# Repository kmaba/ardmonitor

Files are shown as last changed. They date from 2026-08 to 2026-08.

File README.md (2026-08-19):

# ardmonitor

Smart USB desktop monitor running on an Arduino Mega 2560 (or Uno) with a 16×2 I2C LCD, push button, and piezo buzzer.

Supports **Full Mode** (connected to home server) and **Mini / Companion Mode** (lightweight desktop companion for Windows/Linux/macOS).

---

## Features

### 1. Dual Operating Modes
- **Full Homeserver Mode (6 Screens)**:
  - **Clock**: Big 3×2 custom-glyph `HH:MM` display (12-hour, ticking, default screen).
  - **Pi-hole**: DNS request count on the left, blocking percentage on the right.
  - **3D Printer (Moonraker / Klipper)**: Solid+mesh progress bar, remaining time, scrolling filename, temperatures. Auto-switches to this slide when a print starts.
  - **Weather**: Real-time temperature, humidity, wind speed, and weather conditions (Open-Meteo).
  - **Azaan / Prayer Times**: Next prayer name with live countdown in hours/minutes (AlAdhan).
  - **Network**: WiFi SSID, signal strength, and tailnet / local IP.
- **Companion / Mini Mode (3 Screens)**:
  - Automatically activates when running the standalone `companion.py` script.
  - Reduces slides to: **Clock · Weather · Azaan**.

### 2. Physical & Virtual Controls
- **Short Press**: Cycle active screens / navigate menus.
- **Long Press (900ms)**: Open contextual action menu (e.g. Pause/Resume/Cancel print, toggle Pi-hole adblock, manual sync).
- **Super Long Press (3s)**: Toggle LCD backlight on/off.
- **Virtual Button**: Web panel replicates physical button hold gestures (`short`, `long`, `super`).

---

## Hardware & Wiring

- **Board**: Arduino Mega 2560 (recommended for SRAM headroom) or Arduino Uno R3.
- **Display**: 16×2 HD44780 LCD with PCF8574 I2C backpack (Address `0x27`).
- **Button**: Pin **D8** → GND (`INPUT_PULLUP`, active LOW).
- **Buzzer**: Pin **D9** → GND.

### I2C Pin Connections:
| Board | SDA | SCL | VCC | GND |
|---|---|---|---|---|
| **Arduino Mega 2560** | Pin **20** | Pin **21** | 5V | GND |
| **Arduino Uno R3** | Pin **A4** | Pin **A5** | 5V | GND |

---

## Software

### 1. Arduino Firmware (`HomeMonitor.ino`)
Compile and flash using Arduino IDE or `arduino-builder`:
```sh
# For Mega 2560:
arduino-builder -fqbn arduino:avr:mega:cpu=atmega2560 HomeMonitor.ino
# For Uno:
arduino-builder -fqbn arduino:avr:uno HomeMonitor.ino
```

### 2. Standalone Companion App
Cross-platform lightweight driver for Windows, Linux, and macOS. Auto-detects the Arduino on any USB/COM port, sets the Arduino to Mini Mode, and streams local clock, weather, and prayer times:

- **Windows (`companion.bat`)**:
  - Fully automated 1-click bootstrap.
  - Automatically downloads `companion.py` from GitHub if missing.
  - Prompts for UAC and installs Python 3 if not present on the system.
  - Auto-installs `pyserial` and connects to the display.
- **Linux / macOS (`companion.sh`)**:
  - Automatically downloads `companion.py` if missing.
  - Auto-installs Python 3 via system package manager (apt/pacman/dnf/brew) if needed.
  - Auto-installs `pyserial` and runs the driver.
- **Manual**:
  ```sh
  pip install pyserial
  python companion.py
  ```

### 3. Full Home Server Bridge (`homemonitor_bridge.py`)
Runs as a systemd service on a home server or PC connected to the Arduino. Polls Pi-hole v6 API, Moonraker Klipper API, weather, and azaan, and serves a mobile-responsive web controller at `http://localhost:8080`.

---

## 3D Printable Enclosure

The `enclosure.scad` file provides a friction-fit 2-piece case with exact cutouts for the LCD, side USB/power cables, front button, and Arduino PCB standoffs. Pre-rendered STLs (`bottom_shell.stl`, `top_lid.stl`) are included.

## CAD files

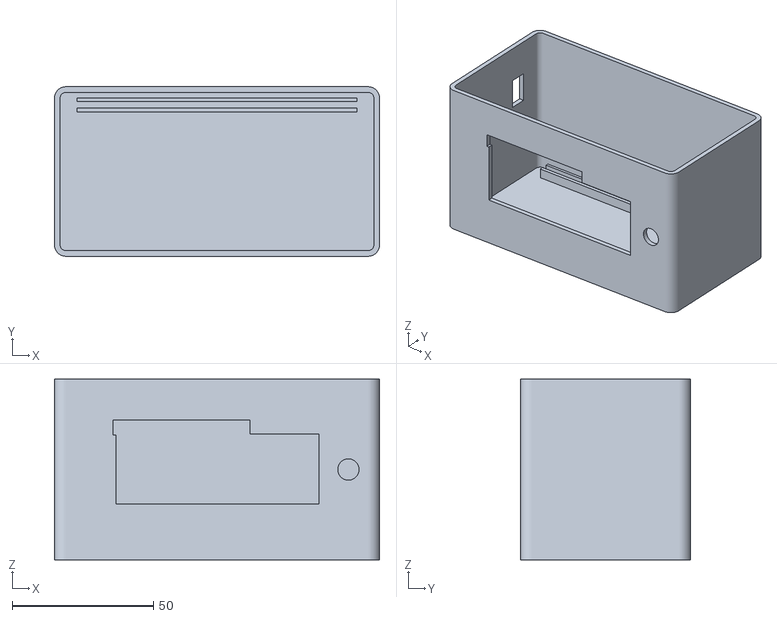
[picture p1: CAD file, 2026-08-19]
bottom_shell.stl
115.0 x 60.0 x 64.0

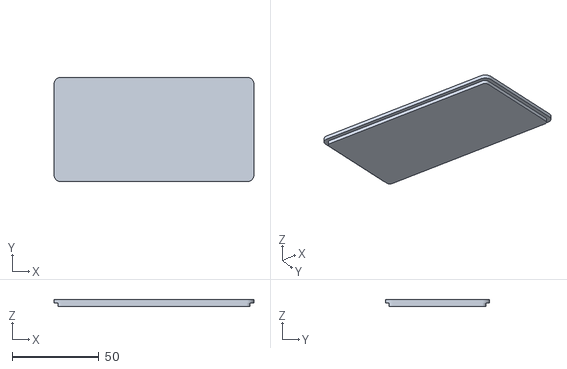
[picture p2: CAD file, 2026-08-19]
top_lid.stl
115.0 x 60.0 x 4.00

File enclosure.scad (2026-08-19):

// Arduino HomeMonitor Enclosure v7 (Optimized Sleek Desktop Edition)
// - Dimensions: 115mm (L) x 60mm (W) x 68mm (H)
// - Wall thickness: 2.0mm, rounded vertical corners (r = 4mm)
// - Front: Centered LCD window + 5mm (0.5cm) pin-clearance notch directly above LCD window
// - Left: Single USB cutout raised +3mm (Center Z = 43mm / 4.3cm) with halved width (Width Y = 7.0mm)

$fn = 60;

/* ===== ENCLOSURE DIMENSIONS ===== */
outer_x = 115.0;
outer_y = 60.0;                 // Slim 60mm depth
outer_z = 68.0;                 // 68mm compact height
wall    = 2.0;                  // 2.0mm wall thickness
corner_r = 4.0;                 // Rounded corners (r = 4mm)
tol     = 0.35;                 // 3D print tolerance
BOX_H   = 64.0;                 // Bottom shell height (Lid = 4.0mm)

/* ===== HELPER: ROUNDED RECTANGLE CUBE ===== */
module rounded_box(dim, r) {
    x = dim[0]; y = dim[1]; z = dim[2];
    hull() {
        translate([r, r, 0]) cylinder(r=r, h=z);
        translate([x - r, r, 0]) cylinder(r=r, h=z);
        translate([r, y - r, 0]) cylinder(r=r, h=z);
        translate([x - r, y - r, 0]) cylinder(r=r, h=z);
    }
}

/* ===== BASE SHELL ===== */
module shell() {
    difference() {
        rounded_box([outer_x, outer_y, outer_z], corner_r);
        // Hollow interior
        translate([wall, wall, wall])
            rounded_box([outer_x - 2*wall, outer_y - 2*wall, outer_z], max(1.0, corner_r - wall));
    }
}

module bottom_box() {
    intersection() {
        shell();
        cube([outer_x, outer_y, BOX_H]);
    }
}

module top_lid() {
    inner_x = outer_x - 2*wall;
    inner_y = outer_y - 2*wall;
    inner_r = max(1.0, corner_r - wall);

    translate([0, 0, BOX_H]) {
        // Inner locating rim (slides into box opening)
        translate([wall + 0.25, wall + 0.25, 0])
            rounded_box([inner_x - 0.5, inner_y - 0.5, outer_z - BOX_H - wall], inner_r);
        // Top plate
        translate([0, 0, outer_z - BOX_H - wall])
            rounded_box([outer_x, outer_y, wall], corner_r);
    }
}

/* ===== FRONT PANEL CUTOUTS (Y = 0) ===== */
LCD_W = 71.5;
LCD_H = 24.5;
LCD_X = (outer_x - LCD_W) / 2;       // 21.75 mm (centered in X)
LCD_Z = (BOX_H - LCD_H) / 2;         // 19.75 mm (centered in Z)

BUTTON_X = 104.0;
BUTTON_Z = LCD_Z + LCD_H / 2;         // Aligned with LCD center
BUTTON_D = 7.2;

// Pin header notch: 48mm wide, exactly 5mm (0.5cm) directly above top edge of LCD
NOTCH_W = 48.0;
NOTCH_H = 5.0;                       // 5mm (0.5cm) height directly above screen cutout

module front_cutouts() {
    // 1. Main LCD glass window
    translate([LCD_X, -1, LCD_Z])
        cube([LCD_W + tol, wall + 2, LCD_H + tol]);

    // 2. 5mm (0.5cm) pin-header notch directly above the LCD window's top edge
    translate([LCD_X - 1, -1, LCD_Z + LCD_H])
        cube([NOTCH_W + tol, wall + 2, NOTCH_H + tol]);

    // 3. Panel button hole
    translate([BUTTON_X, wall + 2, BUTTON_Z])
        rotate([90, 0, 0])
        cylinder(d=BUTTON_D + tol, h=wall + 4);
}

/* ===== LEFT WALL CUTOUTS (X = 0) ===== */
// USB cutout:
// Center: Z = 43.0mm (4.3cm), Y = 44.0mm (4.4cm)
// Width: 7.0mm (halved from 14mm)
// Height: 12.0mm
// Bottom edge of hole: Z = 37.0mm (3.7cm from outer base)
// Top edge of hole: Z = 49.0mm (4.9cm from outer base)
USB_Y = 44.0;
USB_Z = 43.0;                        // Moved +0.3cm (3.0mm) up
USB_W = 7.0;                         // Halved width (7.0mm)
USB_H = 12.0;

module left_cutouts() {
    translate([-1, USB_Y - USB_W/2, USB_Z - USB_H/2])
        cube([wall + 2, USB_W + tol, USB_H + tol]);
}

/* ===== LIGHTWEIGHT MEGA GUIDE RAIL ===== */
module board_guide() {
    // Slim vertical guide rails on the floor
    translate([wall + 6, outer_y - wall - 7, wall])
        difference() {
            cube([outer_x - 2*wall - 12, 5.0, 4.0]);
            translate([-1, 1.5, 1.5])
                cube([outer_x - 2*wall - 10, 2.0 + tol, 3.0]);
        }
}

/* ===== ASSEMBLY ===== */
module assembled() {
    color("DimGray", 0.9) bottom_box();
    color("SlateGray", 0.85) top_lid();

    // Visual: LCD module (Green)
    color("DarkGreen", 0.7)
        translate([(outer_x - 80)/2, wall, LCD_Z - 5])
        cube([80, 9, 36]);

    // Visual: Vertical Mega (Blue)
    color("DodgerBlue", 0.7)
        translate([wall + 4, outer_y - wall - 6, wall + 2])
        cube([101.6, 2.0, 53.3]);
}

/* ===== EXPORTS ===== */
module print_bottom() {
    difference() {
        union() {
            bottom_box();
            board_guide();
        }
        front_cutouts();
        left_cutouts();
    }
}

module print_top() {
    top_lid();
}

assembled();

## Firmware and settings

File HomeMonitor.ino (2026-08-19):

/*
 * HomeMonitor (PC-driven) — Uno + 16x2 I2C LCD (0x27)
 * Buzzer D9, button D8 (button -> GND, INPUT_PULLUP, active LOW).
 *
 * PC streams data (P:/R:/N:/C:/S:/MSG:). Arduino -> PC:
 *   ADBLOCK:ON | ADBLOCK:OFF[:<sec>]
 *   PRINT:PAUSE | PRINT:RESUME | PRINT:CANCEL
 *   GCODE:HOME | GCODE:EXTRUDE | GCODE:RETRACT
 *   TEMP:PLA | TEMP:PETG | TEMP:OFF
 *   PING | NOTIFY | SYNC
 * UI: short press cycles screens; hold opens context menu (bar fills on the
 * BOTTOM row only); in menu short-press moves, long-press selects.
 */
#include <Wire.h>
#include <LiquidCrystal_I2C.h>

LiquidCrystal_I2C lcd(0x27, 16, 2);

const int BUTTON_PIN = 8;    // button -> GND, INPUT_PULLUP, active LOW
const int BUZZER_PIN = 9;

// ---------------- sounds (very quiet, monotone, 25% duty) ----------------
void quietTone(unsigned int freq, unsigned int ms) {
  unsigned long period = 1000000UL / freq;
  unsigned long on = period * 25 / 100;
  unsigned long off = period - on;
  unsigned long end = millis() + ms;
  while ((long)(end - millis()) > 0) {
    digitalWrite(BUZZER_PIN, HIGH);
    delayMicroseconds(on);
    digitalWrite(BUZZER_PIN, LOW);
    delayMicroseconds(off);
  }
  digitalWrite(BUZZER_PIN, LOW);
}
void beep()       { quietTone(440, 40); }
void beepSelect() { quietTone(440, 110); }

// ---------------- screens ----------------
enum { SCR_PIHOLE, SCR_PRINT, SCR_WEATHER, SCR_AZAAN, SCR_NET, SCR_CLOCK, SCR_COUNT };
int screen = SCR_CLOCK;
int prevScreen = -1;
bool companionMode = false;
const char* screenNames[SCR_COUNT] = { "Pi-hole", "Print", "Weather", "Azaan", "Network", "Clock" };

char scrL1[SCR_COUNT][17];
char scrL2[SCR_COUNT][17];
bool scrHas[SCR_COUNT] = { false, false, false, false, false, false };

char printState[10] = "standby";
char printFname[21] = "";
int  pPct = 0, pE = 0, pET = 0, pB = 0, pBT = 0, pElapsed = 0;

// live clock state (from C: line, ticks locally)
byte clkH = 0, clkM = 0, clkS = 0;
int  clkDay = 0, clkMon = 0, clkYr = 0;
char clkBlk[4] = "?";
unsigned long clkSyncMs = 0;
bool clockValid = false;

// pi-hole stats (requests + blocked %)
long piholeQueries = 0;
long piholeBlocked = 0;
int piholePct = 0;
// weather (temp stored as degC * 10, e.g. 234 = 23.4C)
int wTemp10 = 0;
int wHum = 0, wWind = 0, wCode = 0;
// azaan prayer times "HH:MM" (24h)
char az[5][6];

// ---------------- menu ----------------
typedef struct { const char* label; const char* cmd; } MenuItem;

MenuItem piholeMenu[] = {
  { "Back", "" },
  { "Adblock ON", "ADBLOCK:ON" },
  { "Adblock OFF", "ADBLOCK:OFF:0" },
  { "Off 10s", "ADBLOCK:OFF:10" },
  { "Off 30s", "ADBLOCK:OFF:30" },
  { "Off 1m", "ADBLOCK:OFF:60" },
  { "Off 5m", "ADBLOCK:OFF:300" },
  { "Off 1h", "ADBLOCK:OFF:3600" },
};
MenuItem printIdle[] = {
  { "Back", "" },
  { "Home", "GCODE:HOME" },
  { "Extrude 10mm", "GCODE:EXTRUDE" },
  { "Retract 10mm", "GCODE:RETRACT" },
  { "Preheat PLA", "TEMP:PLA" },
  { "Preheat PETG", "TEMP:PETG" },
  { "Cooldown", "TEMP:OFF" },
};
MenuItem printBusy[] = {
  { "Back", "" },
  { "Pause", "PRINT:PAUSE" },
  { "Cancel", "PRINT:CANCEL" },
  { "Cooldown", "TEMP:OFF" },
};
MenuItem printPaused[] = {
  { "Back", "" },
  { "Resume", "PRINT:RESUME" },
  { "Cancel", "PRINT:CANCEL" },
  { "Cooldown", "TEMP:OFF" },
};
MenuItem netMenu[] = {
  { "Back", "" },
  { "Ping server", "PING" },
  { "Notify Discord", "NOTIFY" },
};
MenuItem clockMenu[] = {
  { "Back", "" },
  { "Sync now", "SYNC" },
};
MenuItem simpleMenu[] = {
  { "Back", "" },
  { "Sync now", "SYNC" },
};

MenuItem* menuItems = NULL;
const char* menuTitle = "";
int menuLen = 0;
int menuIdx = 0;

// ---------------- UI state ----------------
enum { ST_SCREEN, ST_MENU } state = ST_SCREEN;

char msg1[17] = "";
char msg2[17] = "";
unsigned long msgUntil = 0;
const unsigned long MSG_MS = 2500;

// ---------------- button (debounced edges, active LOW) ----------------
const unsigned long DEBOUNCE = 50;
const unsigned long LONG_MS = 900;
const unsigned long SUPER_LONG_MS = 3000;

bool redraw = true;                 // force full redraw after a screen switch / data change

bool btnPrev = false;
bool btnNow = false;
unsigned long lastBtnChange = 0;
unsigned long btnDownMs = 0;
bool longFired = false;
bool superLongFired = false;
bool backlightOn = true;
int lastBarCells = -1;

void shortPressAction() {
  beep();
  redraw = true;
  if (state == ST_MENU) {
    menuIdx = (menuIdx + 1) % menuLen;
  } else if (companionMode) {
    // Companion mode: only cycle Weather, Azaan, Clock
    if (screen == SCR_WEATHER) screen = SCR_AZAAN;
    else if (screen == SCR_AZAAN) screen = SCR_CLOCK;
    else screen = SCR_WEATHER;
  } else {
    screen = (screen + 1) % SCR_COUNT;
  }
}

void selectOption() {
  const char* cmd = menuItems[menuIdx].cmd;
  if (strcmp(cmd, "") == 0) {                 // Back
    state = ST_SCREEN;
  } else {
    Serial.println(cmd);
    state = ST_SCREEN;
    strncpy(msg1, menuItems[menuIdx].label, 16); msg1[16] = 0;
    strcpy(msg2, "sent to PC");
    msgUntil = millis() + MSG_MS;
  }
  redraw = true;
}

void enterPrintMenu() {
  if (strcmp(printState, "printing") == 0)      { menuItems = printBusy; menuLen = 4; }
  else if (strcmp(printState, "paused") == 0)   { menuItems = printPaused; menuLen = 4; }
  else                                          { menuItems = printIdle; menuLen = 7; }
  menuTitle = "Print";
}

void longPressAction() {
  beepSelect();
  redraw = true;
  if (state == ST_MENU) {
    selectOption();
  } else {
    state = ST_MENU;
    menuIdx = 0;
    switch (screen) {
      case SCR_PIHOLE:
        menuItems = piholeMenu; menuLen = sizeof(piholeMenu) / sizeof(MenuItem); menuTitle = "Pi-hole"; break;
      case SCR_PRINT:
        enterPrintMenu(); break;
      case SCR_NET:
        menuItems = netMenu; menuLen = sizeof(netMenu) / sizeof(MenuItem); menuTitle = "Network"; break;
      case SCR_CLOCK:
        menuItems = clockMenu; menuLen = sizeof(clockMenu) / sizeof(MenuItem); menuTitle = "Clock"; break;
      case SCR_WEATHER:
      case SCR_AZAAN:
        menuItems = simpleMenu; menuLen = sizeof(simpleMenu) / sizeof(MenuItem); menuTitle = screenNames[screen]; break;
    }
  }
}

void toggleBacklight() {
  backlightOn = !backlightOn;
  if (backlightOn) lcd.backlight(); else lcd.noBacklight();
  beep();
  state = ST_SCREEN;
  redraw = true;
}

void updateButton() {
  unsigned long now = millis();
  bool raw = (digitalRead(BUTTON_PIN) == LOW);
  if (raw != btnPrev) {
    btnPrev = raw;
    lastBtnChange = now;
  }
  if (now - lastBtnChange >= DEBOUNCE) {
    if (raw != btnNow) {
      btnNow = raw;
      if (btnNow) {
        btnDownMs = now;
        longFired = false;
        superLongFired = false;
        lastBarCells = -1;
      } else if (!longFired) {
        shortPressAction();
      }
    }
  }
  if (btnNow && !longFired && (now - btnDownMs) >= LONG_MS) {
    longFired = true;
    longPressAction();
  }
  if (btnNow && !superLongFired && (now - btnDownMs) >= SUPER_LONG_MS) {
    superLongFired = true;
    toggleBacklight();
  }
}

// ---------------- LCD ----------------
char lineCache[2][17];

void lcdLine(int row, const char* s) {
  char line[17];
  strncpy(line, s, 16);
  line[16] = 0;
  for (int i = strlen(line); i < 16; i++) line[i] = ' ';
  line[16] = 0;
  if (!redraw && strncmp(line, lineCache[row], 16) == 0) return;
  strncpy(lineCache[row], line, 16);
  lcd.setCursor(0, row);
  lcd.print(line);
}

// custom bar glyphs: solid fill columns + mesh-hatch for the unfilled track
void createBarChars() {
  for (int fill = 0; fill <= 5; fill++) {
    byte bm[8];
    for (int r = 0; r < 8; r++) {
      byte v = 0;
      for (int c = 0; c < 5; c++) {
        bool on = (c < fill) || ((c + r) % 2 == 0);   // filled=solid, rest=mesh
        if (on) v |= (1 << (4 - c));
      }
      bm[r] = v;
    }
    lcd.createChar(fill, bm);
  }
}

// ---- big 3x2 digits (8 segment glyphs, HD44780 slots 0-7) ----
byte segLT[8]  = { B00111, B11111, B11111, B11111, B11111, B11111, B11111, B11111 };
byte segUB[8]  = { B11111, B11111, B11111, B00000, B00000, B00000, B00000, B00000 };
byte segRT[8]  = { B11100, B11111, B11111, B11111, B11111, B11111, B11111, B11111 };
byte segLL[8]  = { B11111, B11111, B11111, B11111, B11111, B11111, B11111, B00111 };
byte segLB[8]  = { B00000, B00000, B00000, B00000, B00000, B11111, B11111, B11111 };
byte segLR[8]  = { B11111, B11111, B11111, B11111, B11111, B11111, B11111, B11100 };
byte segUMB[8] = { B11111, B11111, B11111, B00000, B00000, B00000, B11111, B11111 };
byte segLMB[8] = { B11111, B00000, B00000, B00000, B00000, B11111, B11111, B11111 };

int glyphMode = 0;   // 0 = bar glyphs (print), 1 = big-digit glyphs (clock)

void createBigDigitChars() {
  lcd.createChar(0, segLT);
  lcd.createChar(1, segUB);
  lcd.createChar(2, segRT);
  lcd.createChar(3, segLL);
  lcd.createChar(4, segLB);
  lcd.createChar(5, segLR);
  lcd.createChar(6, segUMB);
  lcd.createChar(7, segLMB);
}

void ensureBarGlyphs() {
  if (glyphMode == 0) return;
  createBarChars();
  glyphMode = 0;
}

void ensureBigDigitGlyphs() {
  if (glyphMode == 1) return;
  createBigDigitChars();
  glyphMode = 1;
}

void drawBigDigit(int col, int d) {
  // clear the digit cell first so partial digits (1,4,7,9) leave no stale blocks
  lcd.setCursor(col, 0); lcd.print("   ");
  lcd.setCursor(col, 1); lcd.print("   ");
  switch (d) {
    case 0:
      lcd.setCursor(col, 0); lcd.write(0); lcd.write(1); lcd.write(2);
      lcd.setCursor(col, 1); lcd.write(3); lcd.write(4); lcd.write(5); break;
    case 1:
      lcd.setCursor(col + 1, 0); lcd.write(2);
      lcd.setCursor(col + 1, 1); lcd.write(5); break;
    case 2:
      lcd.setCursor(col, 0); lcd.write(6); lcd.write(6); lcd.write(2);
      lcd.setCursor(col, 1); lcd.write(3); lcd.write(7); lcd.write(7); break;
    case 3:
      lcd.setCursor(col, 0); lcd.write(6); lcd.write(6); lcd.write(2);
      lcd.setCursor(col, 1); lcd.write(7); lcd.write(7); lcd.write(5); break;
    case 4:
      lcd.setCursor(col, 0); lcd.write(0); lcd.write(4); lcd.write(2);
      lcd.setCursor(col + 2, 1); lcd.write(5); break;
    case 5:
      lcd.setCursor(col, 0); lcd.write(0); lcd.write(6); lcd.write(6);
      lcd.setCursor(col, 1); lcd.write(7); lcd.write(7); lcd.write(5); break;
    case 6:
      lcd.setCursor(col, 0); lcd.write(0); lcd.write(6); lcd.write(6);
      lcd.setCursor(col, 1); lcd.write(3); lcd.write(7); lcd.write(5); break;
    case 7:
      lcd.setCursor(col, 0); lcd.write(1); lcd.write(1); lcd.write(2);
      lcd.setCursor(col + 2, 1); lcd.write(5); break;
    case 8:
      lcd.setCursor(col, 0); lcd.write(0); lcd.write(6); lcd.write(2);
      lcd.setCursor(col, 1); lcd.write(3); lcd.write(7); lcd.write(5); break;
    case 9:
      lcd.setCursor(col, 0); lcd.write(0); lcd.write(6); lcd.write(2);
      lcd.setCursor(col + 2, 1); lcd.write(5); break;
  }
}

void formatHM(long mins, char* out) {
  if (mins < 0) mins = 0;
  snprintf(out, 8, "%ld:%02ld", mins / 60, mins % 60);
}

// slow scroll window for the filename (half-speed marquee)
void fnameWindow(const char* text, int win, char* out) {
  int len = strlen(text);
  static int sp = 0;
  static unsigned long lastMove = 0;
  if (len > win) {
    if (millis() - lastMove >= 600) {
      lastMove = millis();
      sp++;
      if (sp > len - win) sp = 0;
    }
  } else {
    sp = 0;
  }
  for (int i = 0; i < win; i++) {
    int idx = sp + i;
    out[i] = (idx < len) ? text[idx] : ' ';
  }
  out[win] = 0;
}

// print screen: custom-glyph bar (solid+mesh) + pct on top, remaining + filename below
void renderPrint() {
  static int lastPx = -1, lastPct = -1;
  const int BAR_CHARS = 11;
  int fillPx = (long)pPct * BAR_CHARS * 5 / 100;
  if (redraw || fillPx != lastPx || pPct != lastPct) {
    lastPx = fillPx;
    lastPct = pPct;
    lcd.setCursor(0, 0);
    for (int i = 0; i < BAR_CHARS; i++) {
      int px = fillPx - i * 5;
      lcd.write((uint8_t)(px >= 5 ? 5 : (px > 0 ? px : 0)));
    }
    lcd.write(' ');
    char pbuf[8];
    snprintf(pbuf, 8, "%3d%%", pPct);
    lcd.print(pbuf);
  }

  char l2[17];
  int len = snprintf(l2, 17, "R ");
  char r[8];
  long rem = 0;
  if (pPct > 0) rem = (long)pElapsed * (100 - pPct) / pPct;
  formatHM(rem, r);
  len += snprintf(l2 + len, 17 - len, "%s ", r);
  int win = 16 - len;
  if (win < 3) win = 3;
  fnameWindow(printFname, win, l2 + len);
  lcdLine(1, l2);
}

void currentTime(byte& h, byte& m, byte& s) {
  unsigned long elapsed = (millis() - clkSyncMs) / 1000;
  long ss = clkS + (long)(elapsed % 60);
  long mm = clkM + (long)(elapsed / 60) + ss / 60;
  long hh = clkH + mm / 60;
  s = (byte)(ss % 60);
  m = (byte)(mm % 60);
  h = (byte)(hh % 24);
}

// live ticking big HH:MM clock (12-hour, no AM/PM)
void renderClock(bool first) {
  byte h, m, s;
  currentTime(h, m, s);

  byte h12, md;
  if (!clockValid) {
    h12 = 0; md = 0;                    // 00:00 placeholder until synced
  } else {
    h12 = h % 12; if (h12 == 0) h12 = 12;
    md = m;
  }

  bool colonOn = ((millis() / 500) % 2) == 0;
  static byte lastH = 255, lastM = 255;
  static bool lastColon = false;

  if (first) {
    // just entered the clock screen: clear once, then force full redraw
    lcd.setCursor(0, 0); lcd.print("                ");
    lcd.setCursor(0, 1); lcd.print("                ");
    lastH = 255; lastM = 255; lastColon = !colonOn;
  }

  // incremental: only update the parts that changed (no full-screen clear)
  if (h12 != lastH) {
    lastH = h12;
    drawBigDigit(1, h12 / 10);
    drawBigDigit(5, h12 % 10);
  }
  if (md != lastM) {
    lastM = md;
    drawBigDigit(9, md / 10);
    drawBigDigit(13, md % 10);
  }
  if (colonOn != lastColon) {
    lastColon = colonOn;
    lcd.setCursor(8, 0); lcd.print(colonOn ? ":" : " ");
    lcd.setCursor(8, 1); lcd.print(colonOn ? ":" : " ");
  }
}

// ---- weather ----
const char* weatherDesc(int code) {
  if (code == 0) return "Clear sky";
  if (code == 1) return "Mostly clear";
  if (code == 2) return "Partly cloudy";
  if (code == 3) return "Overcast";
  if (code >= 45 && code <= 48) return "Fog";
  if (code >= 51 && code <= 57) return "Drizzle";
  if (code >= 61 && code <= 67) return "Rain";
  if (code >= 71 && code <= 77) return "Snow";
  if (code >= 80 && code <= 82) return "Showers";
  if (code >= 95 && code <= 99) return "Thunderstorm";
  return "?";
}

void renderWeather() {
  if (!scrHas[SCR_WEATHER]) {
    lcdLine(0, "Weather");
    lcdLine(1, "waiting PC...");
    return;
  }
  char l1[17];
  snprintf(l1, 17, "%d.%dC %d%% %dk/h", wTemp10 / 10, abs(wTemp10 % 10), wHum, wWind);
  lcdLine(0, l1);
  lcdLine(1, weatherDesc(wCode));
}

// ---- azaan: next prayer + countdown ----
void renderAzaan() {
  if (!scrHas[SCR_AZAAN]) {
    lcdLine(0, "Azaan");
    lcdLine(1, "waiting PC...");
    return;
  }
  byte h, m, s;
  currentTime(h, m, s);
  int nowMin = h * 60 + m;

  const char* names[5] = { "Fajr", "Dhuhr", "Asr", "Maghrib", "Isha" };
  int tm[5];
  for (int i = 0; i < 5; i++) {
    tm[i] = ((az[i][0]-'0')*10 + (az[i][1]-'0')) * 60 + ((az[i][3]-'0')*10 + (az[i][4]-'0'));
  }
  int next = -1, nextMin = 0;
  for (int i = 0; i < 5; i++) {
    if (tm[i] > nowMin) { next = i; nextMin = tm[i]; break; }
  }
  if (next < 0) { next = 0; nextMin = tm[0] + 24*60; }   // tomorrow's Fajr

  int diff = nextMin - nowMin;
  char l1[17], l2[17];
  snprintf(l1, 17, "%s %s", names[next], az[next]);
  if (diff >= 60) snprintf(l2, 17, "in %dh %02dm", diff / 60, diff % 60);
  else snprintf(l2, 17, "in %d min", diff);
  lcdLine(0, l1);
  lcdLine(1, l2);
}

// ---- pi-hole: requests left, blocked % right ----
void renderPihole() {
  if (!scrHas[SCR_PIHOLE]) {
    lcdLine(0, "Pi-hole");
    lcdLine(1, "waiting PC...");
    return;
  }
  char l1[17], l2[17];
  snprintf(l1, 17, "Requests   Block");
  snprintf(l2, 17, "%-10ld %4d%%", piholeQueries, piholePct);
  lcdLine(0, l1);
  lcdLine(1, l2);
}

void renderScreen() {
  if (!scrHas[screen]) {
    lcdLine(0, screenNames[screen]);
    lcdLine(1, "waiting PC...");
    return;
  }
  lcdLine(0, scrL1[screen]);
  lcdLine(1, scrL2[screen]);
}

void renderMenu() {
  char buf[17];
  snprintf(buf, 17, "%s %d/%d", menuTitle, menuIdx + 1, menuLen);
  lcdLine(0, buf);
  snprintf(buf, 17, "> %s", menuItems[menuIdx].label);
  lcdLine(1, buf);
}

// bottom-row-only press bar (white squares); top row stays untouched
void renderPressBar() {
  unsigned long dur = millis() - btnDownMs;
  int cells = (int)((long)dur * 16 / LONG_MS);
  if (cells > 16) cells = 16;
  if (cells < 0) cells = 0;
  if (cells != lastBarCells) {
    lastBarCells = cells;
    char bar[17];
    for (int i = 0; i < 16; i++) bar[i] = (i < cells) ? (char)0xFF : ' ';
    bar[16] = 0;
    lcdLine(1, bar);
  }
}

// PC screen removed; this is the main render dispatch
void render() {
  if (btnNow && !longFired) {
    renderPressBar();
    redraw = false;
    prevScreen = -1;
    return;
  }
  if (msgUntil && millis() < msgUntil) {
    lcdLine(0, msg1);
    lcdLine(1, msg2);
    redraw = false;
    prevScreen = -1;
    return;
  }
  if (state == ST_MENU) {
    renderMenu();
    redraw = false;
    prevScreen = -1;
    return;
  }
  if (screen == SCR_PRINT) {
    ensureBarGlyphs();
    renderPrint();
    redraw = false;
    prevScreen = screen;
    return;
  }
  if (screen == SCR_PIHOLE) {
    renderPihole();
    redraw = false;
    prevScreen = screen;
    return;
  }
  if (screen == SCR_WEATHER) {
    renderWeather();
    redraw = false;
    prevScreen = screen;
    return;
  }
  if (screen == SCR_AZAAN) {
    renderAzaan();
    redraw = false;
    prevScreen = screen;
    return;
  }
  if (screen == SCR_CLOCK) {
    ensureBigDigitGlyphs();
    renderClock(screen != prevScreen);
    redraw = false;
    prevScreen = screen;
    return;
  }
  renderScreen();
  redraw = false;
  prevScreen = screen;
}
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
void loop() {
  updateButton();
  drainSerial();
  if (msgUntil && millis() > msgUntil) {
    msgUntil = 0;
    redraw = true;
  }
  render();
  delay(10);
}

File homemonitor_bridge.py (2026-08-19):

#!/usr/bin/env python3
"""
HomeMonitor PC bridge — polls the homeserver (Pi-hole + Moonraker) and the PC's
own stats, streams display data to the Arduino over USB serial, and serves a
web panel to switch slides. Handles commands: ADBLOCK, PRINT, GCODE, TEMP,
PING, NOTIFY, SYNC.
"""
import sys, time, json, glob, subprocess, queue, threading
import urllib.request
from http.server import BaseHTTPRequestHandler, HTTPServer

SERVER = "100.125.116.96"   # kmaba-server tailnet IP (stable)
WEB_PORT = 8080
DISCORD = ("https://discord.com/api/webhooks/1494662807583723560/"
           "CFqfNB9Mqif49FdWwG6zjo6NQ_7LalfB1S-mOn-VqaXiOnZtR7AxsOpUt2ETkecqO9xG")

screen_cmds = queue.Queue()
serial_cmds = queue.Queue()   # generic serial commands (e.g. virtual-button gestures)

last_pst = None            # previous Moonraker print state, for auto-switch
current_pst = "?"          # most recent print state from poll()

PAGE = """<!doctype html><html><head><meta charset="utf-8"><meta name="viewport" content="width=device-width, initial-scale=1"><title>HomeMonitor</title>
<style>
*{box-sizing:border-box}
body{background:#0b0f14;color:#e6e6e6;font-family:system-ui,-apple-system,sans-serif;margin:0;padding:24px 16px;display:flex;justify-content:center}
.wrap{width:100%;max-width:380px;display:flex;flex-direction:column;align-items:center;gap:12px}
h1{font-size:22px;font-weight:600;margin:0 0 4px}
p{color:#8fa3b8;font-size:13px;margin:0 0 8px;text-align:center}
.btn{width:100%;padding:15px;border:none;border-radius:12px;font-size:17px;cursor:pointer;color:#fff;background:#1c2733;border:1px solid #2f4254;-webkit-tap-highlight-color:transparent}
.btn:active{background:#263647}
.btn.on{background:#2e6b4f;border-color:#4d9c78}
.vbtn{width:150px;height:150px;border-radius:50%;border:3px solid #2f4254;background:#1c2733;color:#fff;font-size:20px;display:flex;align-items:center;justify-content:center;cursor:pointer;user-select:none;-webkit-user-select:none;touch-action:none;-webkit-tap-highlight-color:transparent;transition:background .15s;margin-top:8px}
.vbtn.holding{background:#33405a;border-color:#5a7a9c}
.vbtn.held-long{background:#8a6d1f;border-color:#c9a227}
.vbtn.held-super{background:#1f5a8a;border-color:#2a7ac9}
#status{color:#9fb3c8;font-size:13px;min-height:18px;text-align:center}
@media (min-width:600px){ .btn{width:280px} }
</style></head><body>
<div class="wrap">
<h1>HomeMonitor</h1>
<p>choose the slide shown on the Arduino display</p>
<button class="btn" data-n="0">Pi-hole</button>
<button class="btn" data-n="1">Print</button>
<button class="btn" data-n="2">Weather</button>
<button class="btn" data-n="3">Azaan</button>
<button class="btn" data-n="4">Network</button>
<button class="btn" data-n="5">Clock</button>
<p style="margin-top:16px">virtual button &mdash; click: short, hold 1s: menu, hold 3s: backlight</p>
<div class="vbtn" id="vbtn">HOLD</div>
<div id="status"></div>
</div>
<script>
function go(n){fetch('/screen?n='+n).then(function(r){return r.text()}).then(function(){mark(n)}).catch(function(){document.getElementById('status').textContent='failed'});}
function mark(n){var b=document.querySelectorAll('.btn');b.forEach(function(x,i){x.classList.toggle('on',i==n);});}
var b=document.querySelectorAll('.btn');b.forEach(function(x){x.onclick=function(){go(x.getAttribute('data-n'));};});
function sendBtn(a){fetch('/btn?action='+a).then(function(){var m={short:'short press',long:'long press (menu)',super:'backlight toggle'};document.getElementById('status').textContent=m[a]||a;}).catch(function(){document.getElementById('status').textContent='failed'});}
(function(){
  var el=document.getElementById('vbtn'),fired=0,tL,tS;
  function down(e){if(e.cancelable)e.preventDefault();fired=0;el.classList.add('holding');
    tL=setTimeout(function(){fired=1;el.classList.add('held-long');sendBtn('long');},1000);
    tS=setTimeout(function(){fired=2;el.classList.add('held-super');sendBtn('super');},3000);}
  function up(){clearTimeout(tL);clearTimeout(tS);el.classList.remove('holding','held-long','held-super');if(fired===0)sendBtn('short');}
  el.addEventListener('mousedown',down);el.addEventListener('mouseup',up);el.addEventListener('mouseleave',up);
  el.addEventListener('touchstart',down,{passive:false});el.addEventListener('touchend',up);el.addEventListener('touchcancel',up);
})();
</script></body></html>"""

DL_PAGE = """<!doctype html><html><head><meta charset="utf-8"><meta name="viewport" content="width=device-width, initial-scale=1"><title>kmaba.link/d</title>
<style>
body{background:#0b0f14;color:#eee;font-family:system-ui,sans-serif;margin:0;padding:32px 16px;display:flex;justify-content:center}
.wrap{width:100%;max-width:400px}
h1{font-size:24px;margin:0 0 4px}
p{color:#8fa3b8;font-size:14px;margin:0 0 16px}
.card{background:#1c2733;border:1px solid #2f4254;border-radius:12px;padding:20px}
a.dl{display:block;background:#2e6b4f;color:#fff;text-decoration:none;padding:14px;border-radius:10px;text-align:center;font-size:16px;margin:8px 0}
a.dl:hover{background:#3a8764}
h3{font-size:15px;margin:16px 0 6px;color:#e6e6e6}
pre{background:#0d1117;padding:12px;border-radius:8px;overflow-x:auto;font-size:13px;color:#9fb3c8}
</style></head><body>
<div class="wrap">
<h1>kmaba.link/d</h1>
<p>Companion script for the Arduino display — shows time, weather and azaan.</p>
<div class="card">
<a class="dl" href="/companion.py" download>Download for Linux</a>
<a class="dl" href="/companion.py" download>Download for Windows</a>
<h3>Setup</h3>
<pre>pip install pyserial
python companion.py</pre>
<p style="font-size:13px">Plug the Arduino into a USB port, then run the script. It finds the display automatically and streams time, weather and prayer times.</p>
</div>
</div>
</body></html>"""

COMPANION_PATH = "/home/kmaba/companion.py"
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

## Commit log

2026-08-19 Initial commit: Arduino HomeMonitor firmware, bridge, companion app, and enclosure
    [bottom_shell.stl, enclosure.scad, top_lid.stl]
2026-08-19 Update enclosure v4: Mega vertical layout, raised USB, pin header notch, 115x70x75mm
    [bottom_shell.stl, enclosure.scad, top_lid.stl]
2026-08-19 Optimize enclosure v5: 5mm pin notch, centered LCD, flat 60mm depth, rounded r=4mm corners
    [bottom_shell.stl, enclosure.scad, top_lid.stl]
2026-08-19 Update enclosure v6: 5mm pin notch directly above LCD window top edge
    [bottom_shell.stl, enclosure.scad, top_lid.stl]
2026-08-19 Update enclosure v7: USB hole raised +3mm (Z=43mm) and width halved (7mm)
    [bottom_shell.stl, enclosure.scad, top_lid.stl]
